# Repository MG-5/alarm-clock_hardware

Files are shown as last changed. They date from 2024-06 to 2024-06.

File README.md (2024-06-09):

# alarm-clock_v3
Hardware for alarm clock with VFD display

### Requirements for rev 1.0
* 24V input
* efficient boost converter up to 40V
* control VFD display with multiplexing & dimming
* control 24V CCT-LED strip (cold/neutral/warm white) with PWM
* I²C interface
  * DS3231 as RTC
* connection to ESP (UART)
* battery-backup

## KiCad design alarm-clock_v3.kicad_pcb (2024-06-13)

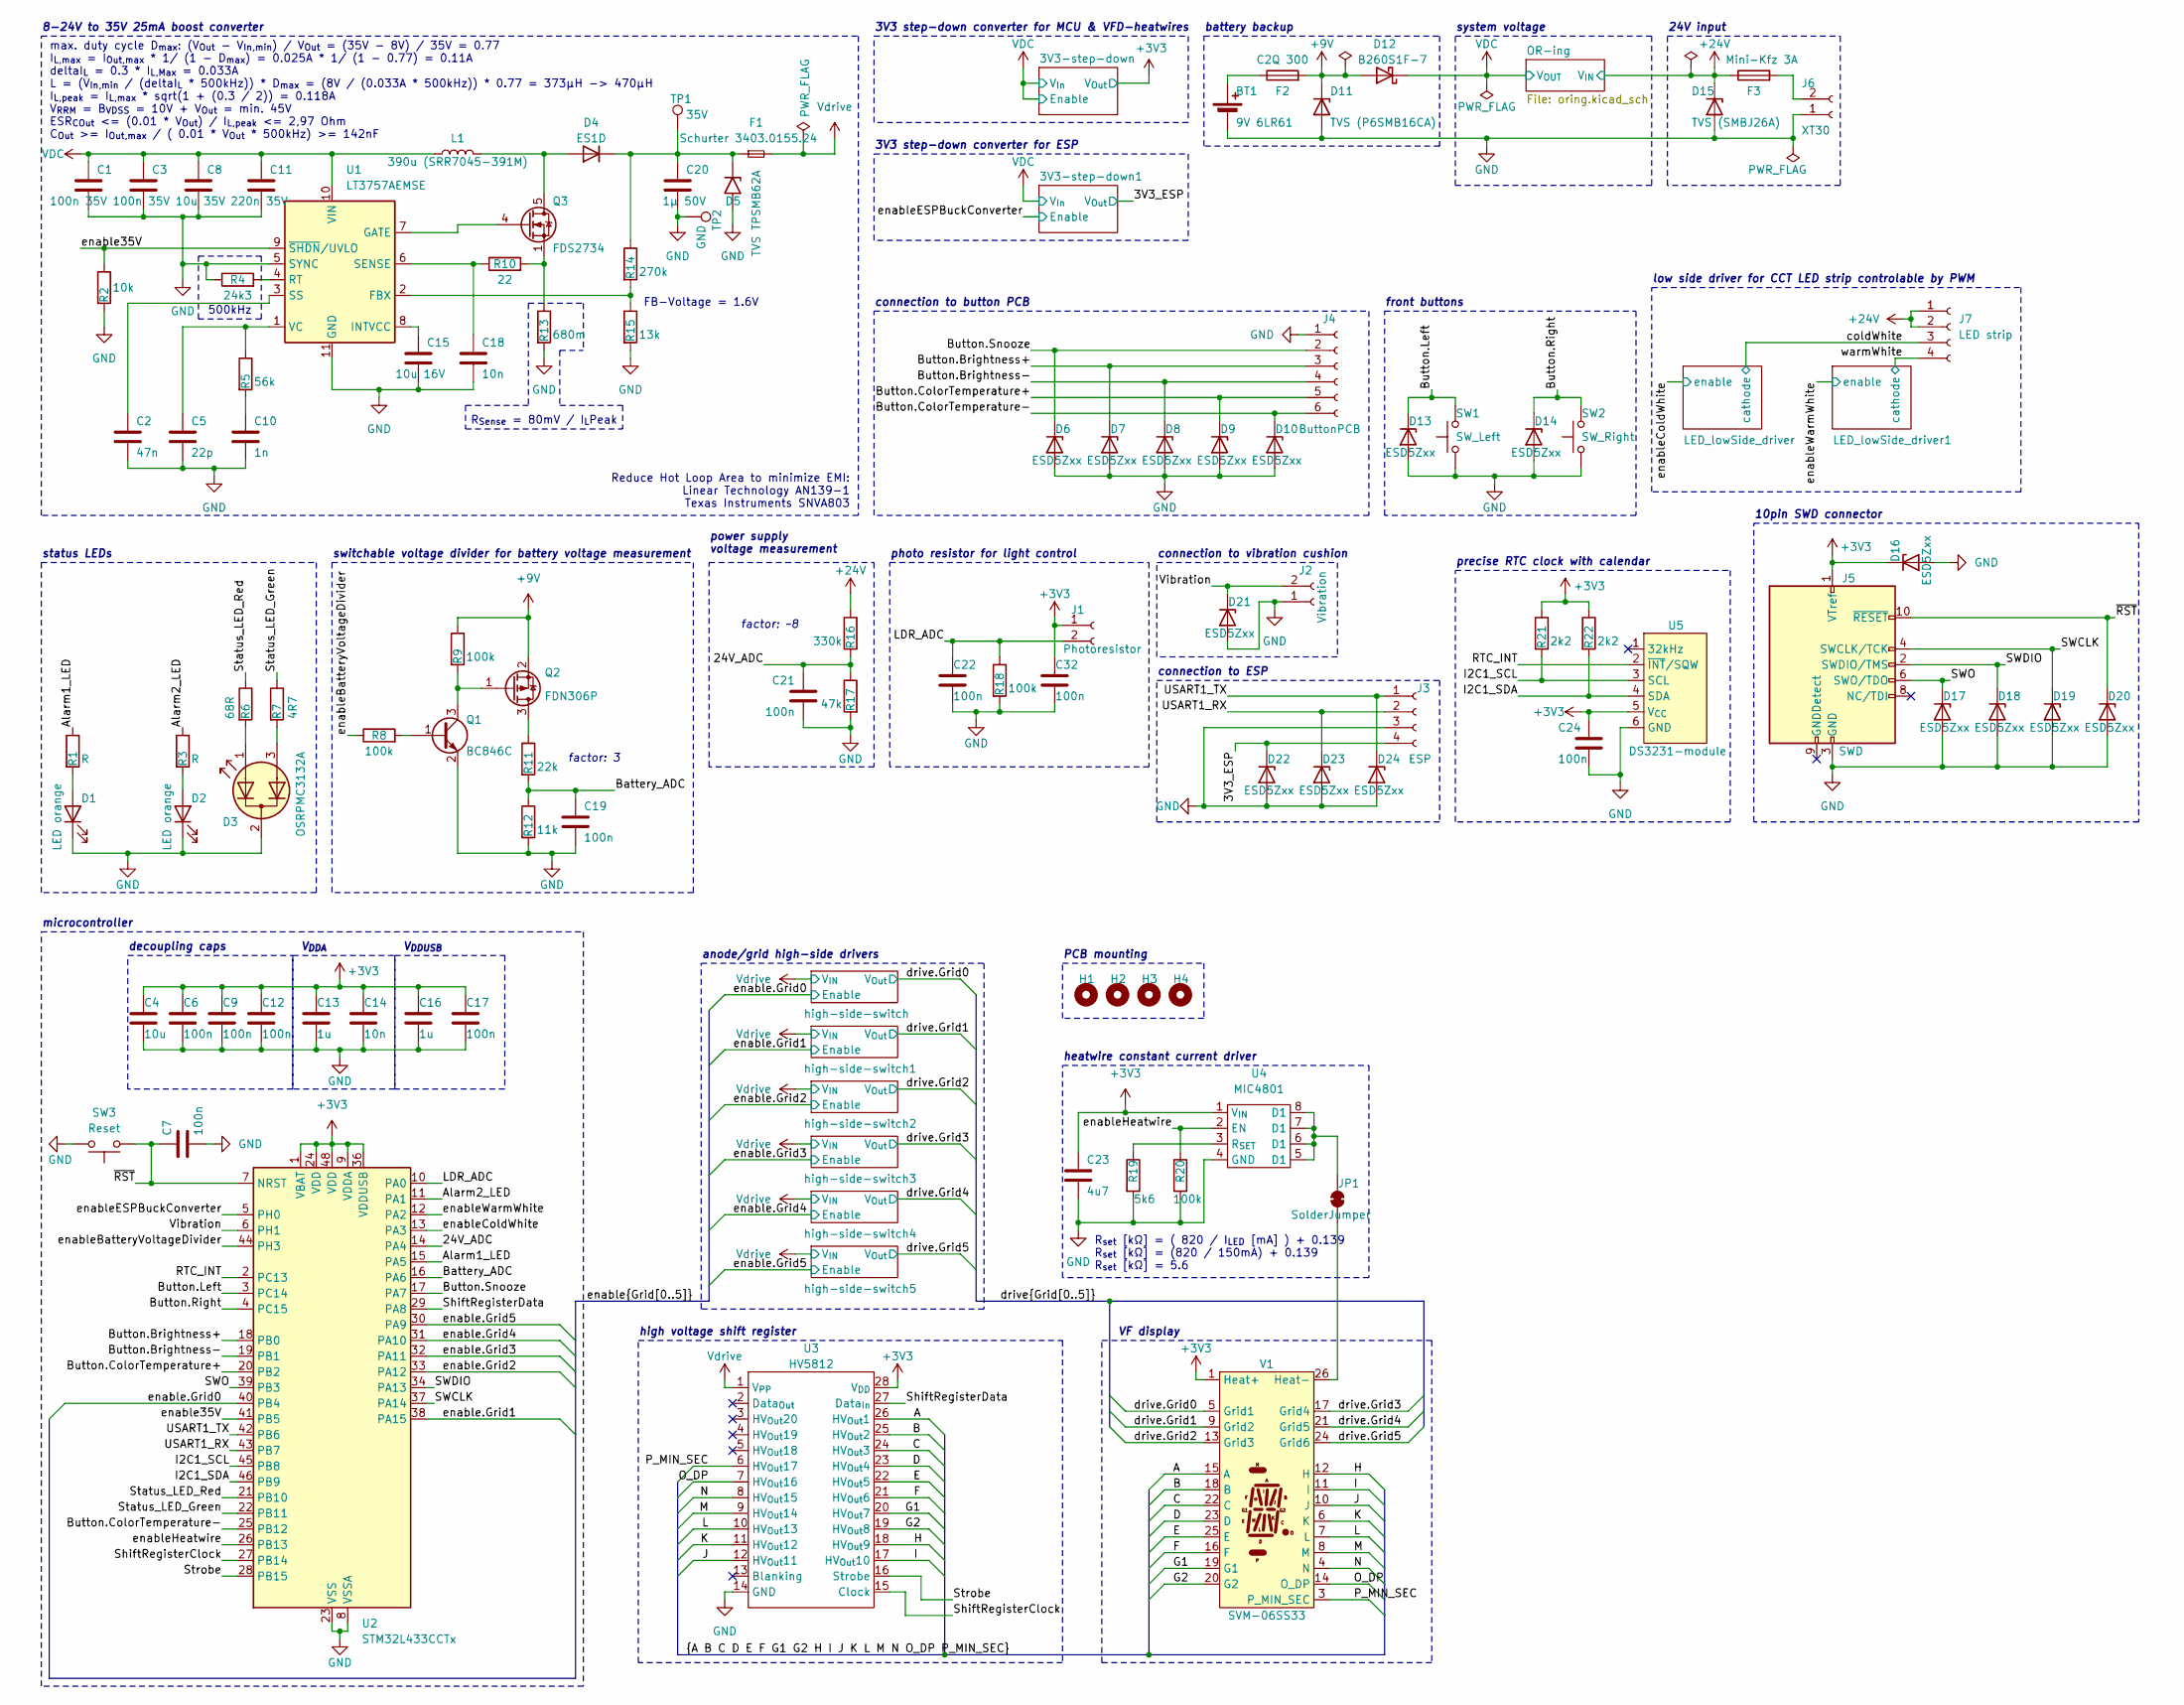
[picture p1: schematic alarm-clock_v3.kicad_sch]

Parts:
BT1: 9V 6LR61; Molex_PicoBlade_53047-0210_1x02_P1.25mm_Vertical
C1, C3: 100n 35V; C_0603_1608Metric_Pad1.08x0.95mm_HandSolder
C2: 47n; C_0603_1608Metric_Pad1.08x0.95mm_HandSolder
C4: 10u; C_0805_2012Metric_Pad1.18x1.45mm_HandSolder
C5: 22p; C_0402_1005Metric_Pad0.74x0.62mm_HandSolder
C6, C7, C9, C12, C17, C19, C21, C22, C24, C32: 100n; C_0603_1608Metric_Pad1.08x0.95mm_HandSolder
C8: 10u 35V; C_1206_3216Metric_Pad1.33x1.80mm_HandSolder
C10: 1n; C_0603_1608Metric_Pad1.08x0.95mm_HandSolder
C11: 220n 35V; C_0805_2012Metric_Pad1.18x1.45mm_HandSolder
C13, C16: 1u; C_0603_1608Metric_Pad1.08x0.95mm_HandSolder
C14: 10n; C_0603_1608Metric_Pad1.08x0.95mm_HandSolder
C15: 10u 16V; C_0805_2012Metric_Pad1.18x1.45mm_HandSolder
C18: 10n; C_0805_2012Metric_Pad1.18x1.45mm_HandSolder
C20: 1µ 50V; C_0805_2012Metric_Pad1.18x1.45mm_HandSolder
C23: 4u7; C_0603_1608Metric_Pad1.08x0.95mm_HandSolder
D1, D2: LED orange; PinHeader_1x02_P2.54mm_Vertical
D3: OSRPMC3132A; PinHeader_1x03_P2.54mm_Vertical
D4: ES1D; D_SMA_Handsoldering
D5: TVS TPSMB62A; D_SMF
D6, D7, D8, D9, D10, D13, D14, D16, D17, D18, D19, D20, D21, D22, D23, D24: ESD5Zxx; D_SOD-523
D11: TVS (P6SMB16CA); D_SMB_Handsoldering
D12: B260S1F-7; D_SOD-123
D15: TVS (SMBJ26A); D_SMB_Handsoldering
F1: Schurter 3403.0155.24; Fuse_Schurter_UMT250
F2: C2Q 300; Fuse_0603_1608Metric_Pad1.05x0.95mm_HandSolder
F3: Mini-Kfz 3A; KEYSTONE-FUSE-3557-2
H1, H2, H3, H4: MountingHole; MountingHole_3.2mm_M3_ISO14580
J1: Photoresistor; Molex_PicoBlade_53047-0210_1x02_P1.25mm_Vertical
J2: Vibration; Molex_PicoBlade_53047-0210_1x02_P1.25mm_Vertical
J3: ESP; Molex_PicoBlade_53047-0410_1x04_P1.25mm_Vertical
J4: ButtonPCB; Molex_PicoBlade_53047-0610_1x06_P1.25mm_Vertical
J5: SWD; PinHeader_2x05_P1.27mm_Vertical_SMD
J6: XT30; AMASS_XT30U-M_1x02_P5.0mm_Vertical
J7: LED strip; Molex_PicoBlade_53047-0410_1x04_P1.25mm_Vertical
JP1: SolderJumper; SolderJumper-2_P1.3mm_Open_TrianglePad1.0x1.5mm
L1: 390u (SRR7045-391M); L_7.3x7.3_H4.5
Q1: BC846C; SOT-23_Handsoldering
Q2: FDN306P; SOT-23_Handsoldering
Q3: FDS2734; SOIC-8_3.9x4.9mm_P1.27mm
R1, R3: R; R_0603_1608Metric_Pad0.98x0.95mm_HandSolder
R2: 10k; R_0603_1608Metric_Pad0.98x0.95mm_HandSolder
R4: 24k3; R_0603_1608Metric_Pad0.98x0.95mm_HandSolder
R5: 56k; R_0603_1608Metric_Pad0.98x0.95mm_HandSolder
R6: 68R; R_0603_1608Metric_Pad0.98x0.95mm_HandSolder
R7: 4R7; R_0603_1608Metric_Pad0.98x0.95mm_HandSolder
R8, R9, R18, R20: 100k; R_0603_1608Metric_Pad0.98x0.95mm_HandSolder
R10: 22; R_0603_1608Metric_Pad0.98x0.95mm_HandSolder
R11: 22k; R_0603_1608Metric_Pad0.98x0.95mm_HandSolder
R12: 11k; R_0603_1608Metric_Pad0.98x0.95mm_HandSolder
R13: 680m; R_0603_1608Metric_Pad0.98x0.95mm_HandSolder
R14: 270k; R_0603_1608Metric_Pad0.98x0.95mm_HandSolder
R15: 13k; R_0603_1608Metric_Pad0.98x0.95mm_HandSolder
R16: 330k; R_0603_1608Metric_Pad0.98x0.95mm_HandSolder
R17: 47k; R_0603_1608Metric_Pad0.98x0.95mm_HandSolder
R19: 5k6; R_0603_1608Metric_Pad0.98x0.95mm_HandSolder
R21, R22: 2k2; R_0603_1608Metric_Pad0.98x0.95mm_HandSolder
SW1: SW_Left; SW_SPST_PTS810
SW2: SW_Right; SW_SPST_PTS810
SW3: Reset; SW_SPST_PTS810
TP1: 35V; TestPoint_THTPad_D1.5mm_Drill0.7mm
TP2: GND; TestPoint_THTPad_D1.5mm_Drill0.7mm
U1: LT3757AEMSE; MSOP-10-1EP_3x3mm_P0.5mm_EP1.68x1.88mm
U2: STM32L433CCTx; LQFP-48_7x7mm_P0.5mm
U3: HV5812; SOIC-28W_7.5x17.9mm_P1.27mm
U4: MIC4801; PowerIntegrations_SO-8
U5: DS3231-module
V1: SVM-06SS33

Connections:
+3V3: C4.1, C6.1, C9.1, C12.1, C13.1, C14.1, C16.1, C17.1, C23.1, C24.1, C32.1, D16.1 (K), J1.1, J5.1 (VTref), R21.1, R22.1, U2.1 (VBAT), U2.9 (VDDA), U2.24 (VDD), U2.36 (VDDUSB), U2.48 (VDD), U3.28 (V_{DD}), U4.1 (V_{IN}), U5.5 (V_{CC}), V1.1 (Heat+), V1.2 (Heat+); also elsewhere on the board
+9V: D11.1 (K), D12.2 (A), F2.2, Q2.2 (S), R9.1
+24V: D15.1 (K), F3.1, J7.1, J7.2, R16.1; also elsewhere on the board
/3V3_ESP: D22.1 (K), J3.4; also elsewhere on the board
/24V_ADC: C21.1, R16.2, R17.1, U2.14 (PA4)
/A: U3.26 (HV_{Out}1), V1.15 (A)
/Alarm1_LED: R1.1, U2.15 (PA5)
/Alarm2_LED: R3.1, U2.11 (PA1)
/B: U3.25 (HV_{Out}2), V1.18 (B)
/Battery_ADC: C19.1, R11.2, R12.1, U2.16 (PA6)
/Button.Brightness+: D7.1 (K), J4.3, U2.18 (PB0)
/Button.Brightness-: D8.1 (K), J4.4, U2.19 (PB1)
/Button.ColorTemperature+: D9.1 (K), J4.5, U2.20 (PB2)
/Button.ColorTemperature-: D10.1 (K), J4.6, U2.25 (PB12)
/Button.Left: D13.1 (K), SW1.2, U2.3 (PC14)
/Button.Right: D14.1 (K), SW2.2, U2.4 (PC15)
/Button.Snooze: D6.1 (K), J4.2, U2.17 (PA7)
/C: U3.24 (HV_{Out}3), V1.22 (C)
/D: U3.23 (HV_{Out}4), V1.23 (D)
/E: U3.22 (HV_{Out}5), V1.25 (E)
/F: U3.21 (HV_{Out}6), V1.16 (F)
/G1: U3.20 (HV_{Out}7), V1.19 (G1)
/G2: U3.19 (HV_{Out}8), V1.20 (G2)
/H: U3.18 (HV_{Out}9), V1.12 (H)
/I: U3.17 (HV_{Out}10), V1.11 (I)
/I2C1_SCL: R21.2, U2.45 (PB8), U5.3 (SCL)
/I2C1_SDA: R22.2, U2.46 (PB9), U5.4 (SDA)
/J: U3.12 (HV_{Out}11), V1.10 (J)
/K: U3.11 (HV_{Out}12), V1.6 (K)
/L: U3.10 (HV_{Out}13), V1.7 (L)
/LDR_ADC: C22.1, J1.2, R18.1, U2.10 (PA0)
/M: U3.9 (HV_{Out}14), V1.8 (M)
/N: U3.8 (HV_{Out}15), V1.4 (N)
/O_DP: U3.7 (HV_{Out}16), V1.14 (O_DP)
/P_MIN_SEC: U3.6 (HV_{Out}17), V1.3 (P_MIN_SEC)
/RTC_INT: U2.2 (PC13), U5.2 (~INT/SQW)
/SWCLK: D19.1 (K), J5.4 (SWCLK/TCK), U2.37 (PA14)
/SWDIO: D18.1 (K), J5.2 (SWDIO/TMS), U2.34 (PA13)
/SWO: D17.1 (K), J5.6 (SWO/TDO), U2.39 (PB3)
/ShiftRegisterClock: U2.27 (PB14), U3.15 (Clock)
/ShiftRegisterData: U2.29 (PA8), U3.27 (Data_{In})
/Status_LED_Green: R7.1, U2.22 (PB11)
/Status_LED_Red: R6.1, U2.21 (PB10)
/Strobe: U2.28 (PB15), U3.16 (Strobe)
/USART1_RX: D23.1 (K), J3.2, U2.43 (PB7)
/USART1_TX: D24.1 (K), J3.1, U2.42 (PB6)
/Vibration: D21.1 (K), J2.2, U2.6 (PH1)
/coldWhite: J7.3; also elsewhere on the board
/drive.Grid0: V1.5 (Grid1); also elsewhere on the board
/drive.Grid1: V1.9 (Grid2); also elsewhere on the board
/drive.Grid2: V1.13 (Grid3); also elsewhere on the board
/drive.Grid3: V1.17 (Grid4); also elsewhere on the board
/drive.Grid4: V1.21 (Grid5); also elsewhere on the board
/drive.Grid5: V1.24 (Grid6); also elsewhere on the board
/enable35V: R2.1, U1.9 (~SHDN/UVLO), U2.41 (PB5)
/enable.Grid0: U2.40 (PB4); also elsewhere on the board
/enable.Grid1: U2.38 (PA15); also elsewhere on the board
/enable.Grid2: U2.33 (PA12); also elsewhere on the board
/enable.Grid3: U2.32 (PA11); also elsewhere on the board
/enable.Grid4: U2.31 (PA10); also elsewhere on the board
/enable.Grid5: U2.30 (PA9); also elsewhere on the board
/enableBatteryVoltageDivider: R8.1, U2.44 (PH3)
/enableColdWhite: U2.13 (PA3); also elsewhere on the board
/enableESPBuckConverter: U2.5 (PH0); also elsewhere on the board
/enableHeatwire: R20.1, U2.26 (PB13), U4.2 (EN)
/enableWarmWhite: U2.12 (PA2); also elsewhere on the board
/warmWhite: J7.4; also elsewhere on the board
/~RST: C7.1, D20.1 (K), J5.10 (~RESET), SW3.1, U2.7 (NRST)
GND: BT1.2 (-), C1.2, C2.2, C3.2, C4.2, C5.2, C6.2, C7.2, C8.2, C9.2, C10.2, C11.2, C12.2, C13.2, C14.2, C15.2, C16.2, C17.2, C18.2, C19.2, C20.2, C21.2, C22.2, C23.2, C24.2, C32.2, D1.1 (K), D2.1 (K), D3.2 (K), D5.2 (A2), D6.2 (A), D7.2 (A), D8.2 (A), D9.2 (A), D10.2 (A), D11.2 (A), D13.2 (A), D14.2 (A), D15.2 (A), D16.2 (A), D17.2 (A), D18.2 (A), D19.2 (A), D20.2 (A), D21.2 (A), D22.2 (A), D23.2 (A), D24.2 (A), J2.1, J3.3, J4.1, J5.3 (GND), J5.5 (GND), J6.1, Q1.2 (E), R2.2, R4.1, R12.2, R13.2, R15.2, R17.2, R18.2, R19.2, R20.2, SW1.1, SW2.1, SW3.2, TP2.1, U1.5 (SYNC), U1.11 (GND), U2.8 (VSSA), U2.23 (VSS), U2.35 (VSS), U2.47 (VSS), U3.14 (GND), U4.4 (GND), U5.6 (GND); also elsewhere on the board
unnamed: BT1.1 (+), F2.1
unnamed: C10.1, R5.2
unnamed: D1.2 (A), R1.2
unnamed: D2.2 (A), R3.2
unnamed: D3.1 (A1), R6.2
unnamed: D3.3 (A2), R7.2
unnamed: D4.2 (A), L1.2, Q3.5 (D), Q3.6 (D), Q3.7 (D), Q3.8 (D)
unnamed: C20.1, D4.1 (K), D5.1 (A1), F1.1, R14.1, TP1.1
unnamed: F3.2, J6.2
unnamed: JP1.1 (A), U4.5 (D1), U4.6 (D1), U4.7 (D1), U4.8 (D1)
unnamed: JP1.2 (B), V1.26 (Heat-)
unnamed: Q1.1 (B), R8.2
unnamed: Q1.3 (C), Q2.1 (G), R9.2
unnamed: Q2.3 (D), R11.1
unnamed: Q3.4 (G), U1.7 (GATE)
unnamed: Q3.1 (S), Q3.2 (S), Q3.3 (S), R10.2, R13.1
unnamed: R14.2, R15.1, U1.2 (FBX)
unnamed: C15.1, U1.8 (INTVCC)
unnamed: R4.2, U1.4 (RT)
unnamed: C18.1, R10.1, U1.6 (SENSE)
unnamed: C2.1, U1.3 (SS)
unnamed: C5.1, R5.1, U1.1 (VC)
unnamed: R19.1, U4.3 (R_{SET})
VDC: C1.1, C3.1, C8.1, C11.1, D12.1 (K), L1.1, U1.10 (VIN); also elsewhere on the board
Vdrive: F1.2, U3.1 (V_{PP}); also elsewhere on the board

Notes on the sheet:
24V input
decoupling caps
factor: 3
microcontroller
V_{DDUSB}
factor: ~8
heatwire constant current driver
status LEDs
8-24V to 35V 25mA boost converter
system voltage
connection to ESP
power supply voltage measurement
R_{Sense} = 80mV / I_{L}Peak
3V3 step-down converter for MCU & VFD-heatwires
front buttons
Reduce Hot Loop Area to minimize EMI: Linear Technology AN139-1 Texas Instruments SNVA803
PCB mounting
battery backup
connection to button PCB
precise RTC clock with calendar
photo resistor for light control
low side driver for CCT LED strip controlable by PWM
3V3 step-down converter for ESP
500kHz
high voltage shift register
FB-Voltage = 1.6V
anode/grid high-side drivers
10pin SWD connector
R_{set} [kΩ] = ( 820 / I_{LED} [mA] ) + 0.139 R_{set} [kΩ] = (820 / 150mA) + 0.139 R_{set} [kΩ] = 5.6
connection to vibration cushion
VF display
switchable voltage divider for battery voltage measurement
max. duty cycle D_{max}: (V_{Out} - V_{In,min}) / V_{Out} = (35V - 8V) / 35V = 0.77 I_{L,max} = I_{Out,max} * 1/ (1 - D_{max}) = 0.025A * 1/ (1 - 0.77) = 0.11A deltaI_{L} = 0.3 * I_{L,Max} = 0.033A L = (V_{In,min} / (deltaI_{L} * 500kHz)) * D_{max} = (8V / (0.033A * 500kHz)) * 0.77 = 373µH -> 470µH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
V_{DDA}

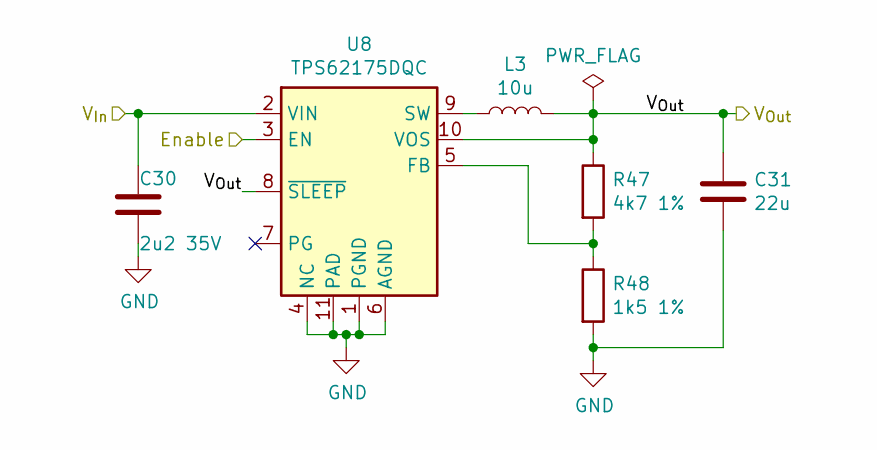
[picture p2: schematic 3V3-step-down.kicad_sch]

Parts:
C30: 2u2 35V; C_0603_1608Metric_Pad1.08x0.95mm_HandSolder
C31: 22u; C_0805_2012Metric_Pad1.18x1.45mm_HandSolder
L3: 10u; L_1210_3225Metric
R47: 4k7 1%; R_0603_1608Metric_Pad0.98x0.95mm_HandSolder
R48: 1k5 1%; R_0603_1608Metric_Pad0.98x0.95mm_HandSolder
U8: TPS62175DQC; WSON-10-1EP_2x3mm_P0.5mm_EP0.84x2.4mm_ThermalVias

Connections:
/3V3_ESP: C31.1, L3.2, R47.1, U8.8 (~SLEEP), U8.10 (VOS); also elsewhere on the board
/enableESPBuckConverter: U8.3 (EN); also elsewhere on the board
GND: C30.2, C31.2, R48.2, U8.1 (PGND), U8.4 (NC), U8.6 (AGND), U8.11 (PAD); also elsewhere on the board
unnamed: R47.2, R48.1, U8.5 (FB)
unnamed: L3.1, U8.9 (SW)
VDC: C30.1, U8.2 (VIN); also elsewhere on the board

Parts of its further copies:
C28: 2u2 35V; C_0603_1608Metric_Pad1.08x0.95mm_HandSolder
C29: 22u; C_0805_2012Metric_Pad1.18x1.45mm_HandSolder
L2: 10u; L_1210_3225Metric
R45: 4k7 1%; R_0603_1608Metric_Pad0.98x0.95mm_HandSolder
R46: 1k5 1%; R_0603_1608Metric_Pad0.98x0.95mm_HandSolder
U7: TPS62175DQC; WSON-10-1EP_2x3mm_P0.5mm_EP0.84x2.4mm_ThermalVias

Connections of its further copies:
+3V3: C29.1, L2.2, R45.1, U7.8 (~SLEEP), U7.10 (VOS); also elsewhere on the board
GND: C28.2, C29.2, R46.2, U7.1 (PGND), U7.4 (NC), U7.6 (AGND), U7.11 (PAD); also elsewhere on the board
unnamed: R45.2, R46.1, U7.5 (FB)
unnamed: L2.1, U7.9 (SW)
VDC: C28.1, U7.2 (VIN), U7.3 (EN); also elsewhere on the board

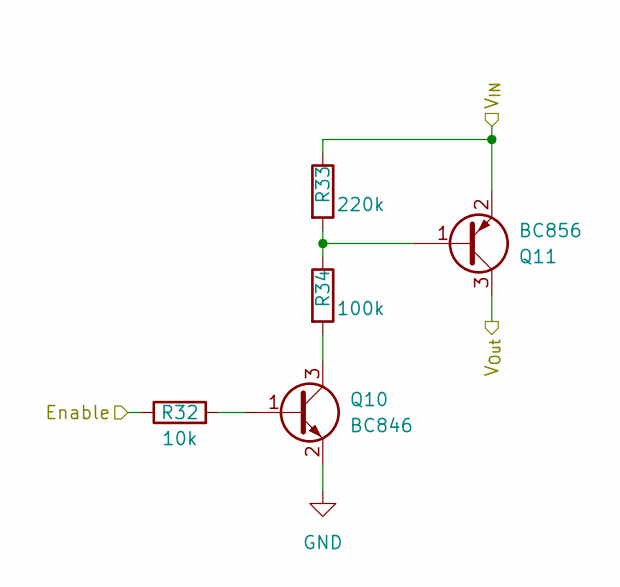
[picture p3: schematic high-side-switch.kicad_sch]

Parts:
Q10: BC846; SOT-23_Handsoldering
Q11: BC856; SOT-23_Handsoldering
R32: 10k; R_0603_1608Metric_Pad0.98x0.95mm_HandSolder
R33: 220k; R_0603_1608Metric_Pad0.98x0.95mm_HandSolder
R34: 100k; R_0603_1608Metric_Pad0.98x0.95mm_HandSolder

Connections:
/drive.Grid3: Q11.3 (C); also elsewhere on the board
/enable.Grid3: R32.1; also elsewhere on the board
GND: Q10.2 (E); also elsewhere on the board
unnamed: Q10.1 (B), R32.2
unnamed: Q10.3 (C), R34.2
unnamed: Q11.1 (B), R33.2, R34.1
Vdrive: Q11.2 (E), R33.1; also elsewhere on the board

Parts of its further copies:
Q4, Q6, Q8, Q12, Q14: BC846; SOT-23_Handsoldering
Q5, Q7, Q9, Q13, Q15: BC856; SOT-23_Handsoldering
R23, R26, R29, R35, R38: 10k; R_0603_1608Metric_Pad0.98x0.95mm_HandSolder
R24, R27, R30, R36, R39: 220k; R_0603_1608Metric_Pad0.98x0.95mm_HandSolder
R25, R28, R31, R37, R40: 100k; R_0603_1608Metric_Pad0.98x0.95mm_HandSolder

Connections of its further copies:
/drive.Grid0: Q5.3 (C); also elsewhere on the board
/drive.Grid1: Q7.3 (C); also elsewhere on the board
/drive.Grid2: Q9.3 (C); also elsewhere on the board
/drive.Grid4: Q13.3 (C); also elsewhere on the board
/drive.Grid5: Q15.3 (C); also elsewhere on the board
/enable.Grid0: R23.1; also elsewhere on the board
/enable.Grid1: R26.1; also elsewhere on the board
/enable.Grid2: R29.1; also elsewhere on the board
/enable.Grid4: R35.1; also elsewhere on the board
/enable.Grid5: R38.1; also elsewhere on the board
GND: Q4.2 (E), Q6.2 (E), Q8.2 (E), Q12.2 (E), Q14.2 (E); also elsewhere on the board
unnamed: Q4.1 (B), R23.2
unnamed: Q4.3 (C), R25.2
unnamed: Q5.1 (B), R24.2, R25.1
unnamed: Q6.1 (B), R26.2
unnamed: Q6.3 (C), R28.2
unnamed: Q7.1 (B), R27.2, R28.1
unnamed: Q8.1 (B), R29.2
unnamed: Q8.3 (C), R31.2
unnamed: Q9.1 (B), R30.2, R31.1
unnamed: Q12.1 (B), R35.2
unnamed: Q12.3 (C), R37.2
unnamed: Q13.1 (B), R36.2, R37.1
unnamed: Q14.1 (B), R38.2
unnamed: Q14.3 (C), R40.2
unnamed: Q15.1 (B), R39.2, R40.1
Vdrive: Q5.2 (E), Q7.2 (E), Q9.2 (E), Q13.2 (E), Q15.2 (E), R24.1, R27.1, R30.1, R36.1, R39.1; also elsewhere on the board

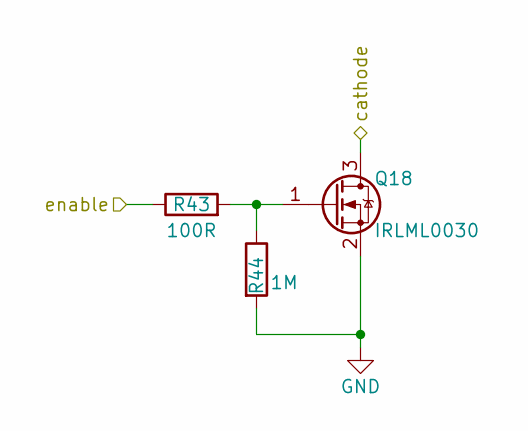
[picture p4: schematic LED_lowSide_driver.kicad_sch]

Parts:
Q18: IRLML0030; SOT-23_Handsoldering
R43: 100R; R_0603_1608Metric_Pad0.98x0.95mm_HandSolder
R44: 1M; R_0603_1608Metric_Pad0.98x0.95mm_HandSolder

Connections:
/enableWarmWhite: R43.1; also elsewhere on the board
/warmWhite: Q18.3 (D); also elsewhere on the board
GND: Q18.2 (S), R44.2; also elsewhere on the board
unnamed: Q18.1 (G), R43.2, R44.1

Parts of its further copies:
Q17: IRLML0030; SOT-23_Handsoldering
R41: 100R; R_0603_1608Metric_Pad0.98x0.95mm_HandSolder
R42: 1M; R_0603_1608Metric_Pad0.98x0.95mm_HandSolder

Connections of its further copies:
/coldWhite: Q17.3 (D); also elsewhere on the board
/enableColdWhite: R41.1; also elsewhere on the board
GND: Q17.2 (S), R42.2; also elsewhere on the board
unnamed: Q17.1 (G), R41.2, R42.1

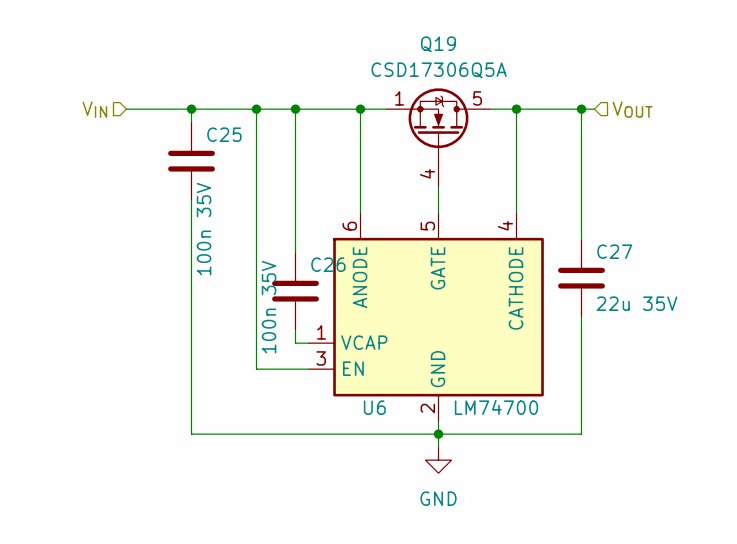
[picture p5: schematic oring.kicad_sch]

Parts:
C25, C26: 100n 35V; C_0603_1608Metric_Pad1.08x0.95mm_HandSolder
C27: 22u 35V; C_0805_2012Metric_Pad1.18x1.45mm_HandSolder
Q19: CSD17306Q5A; TDSON-8-1
U6: LM74700; SOT-23-6

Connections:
+24V: C25.1, C26.1, Q19.1 (S), Q19.2 (S), Q19.3 (S), U6.3 (EN), U6.6 (ANODE); also elsewhere on the board
GND: C25.2, C27.2, U6.2 (GND); also elsewhere on the board
unnamed: Q19.4 (G), U6.5 (GATE)
unnamed: C26.2, U6.1 (VCAP)
VDC: C27.1, Q19.5 (D), U6.4 (CATHODE); also elsewhere on the board

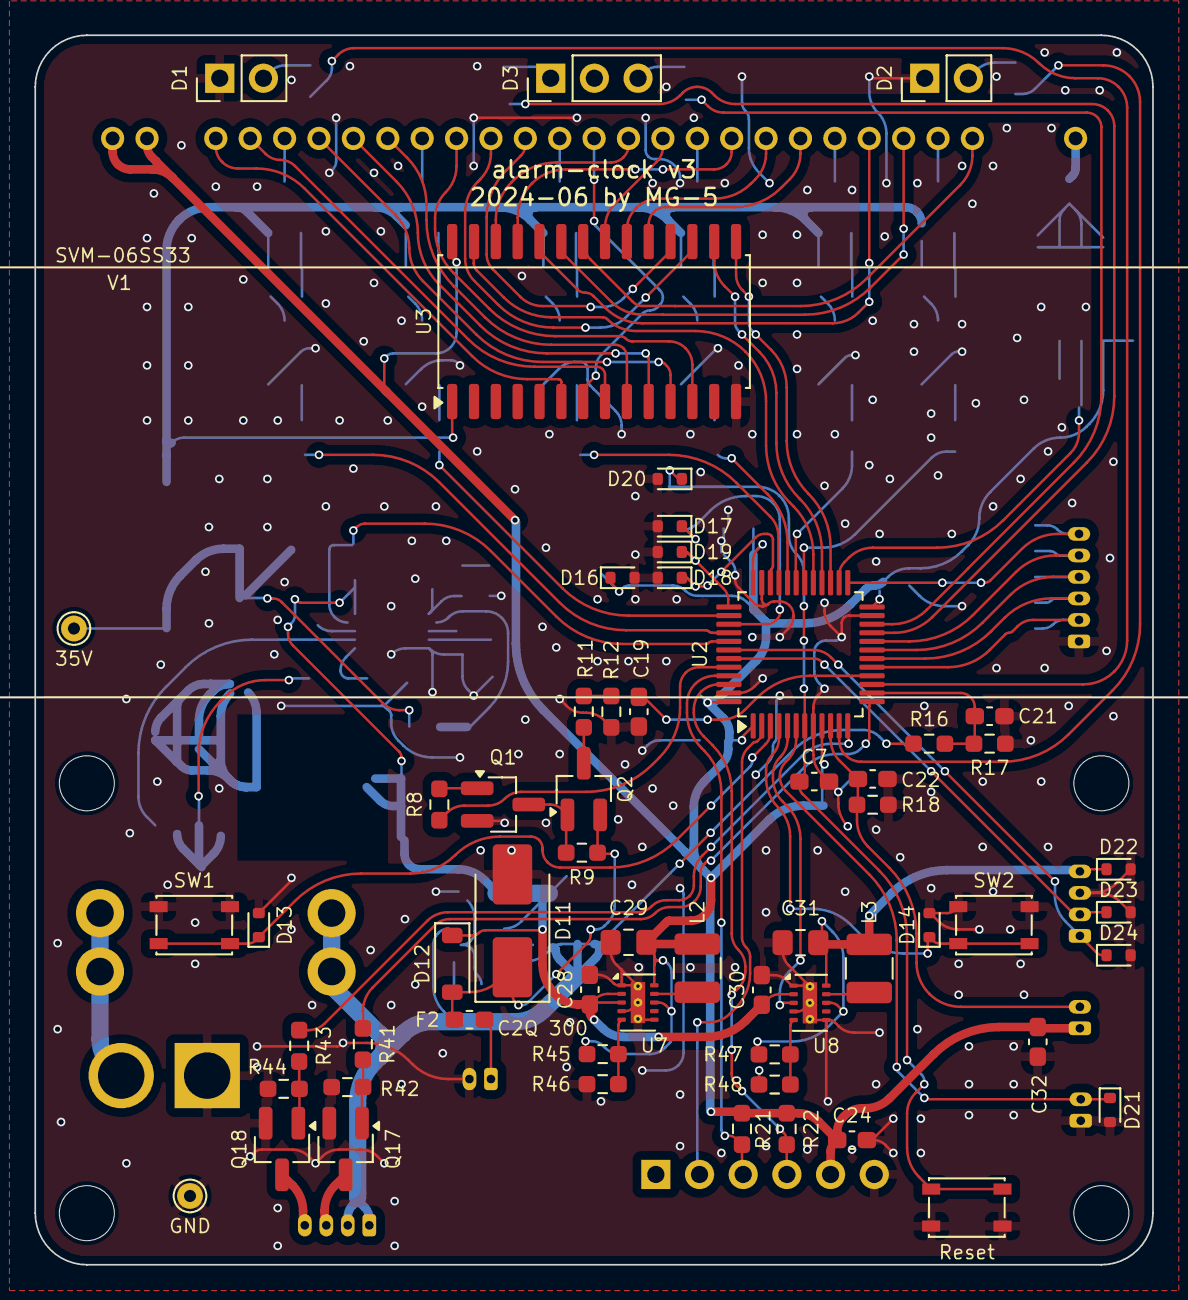
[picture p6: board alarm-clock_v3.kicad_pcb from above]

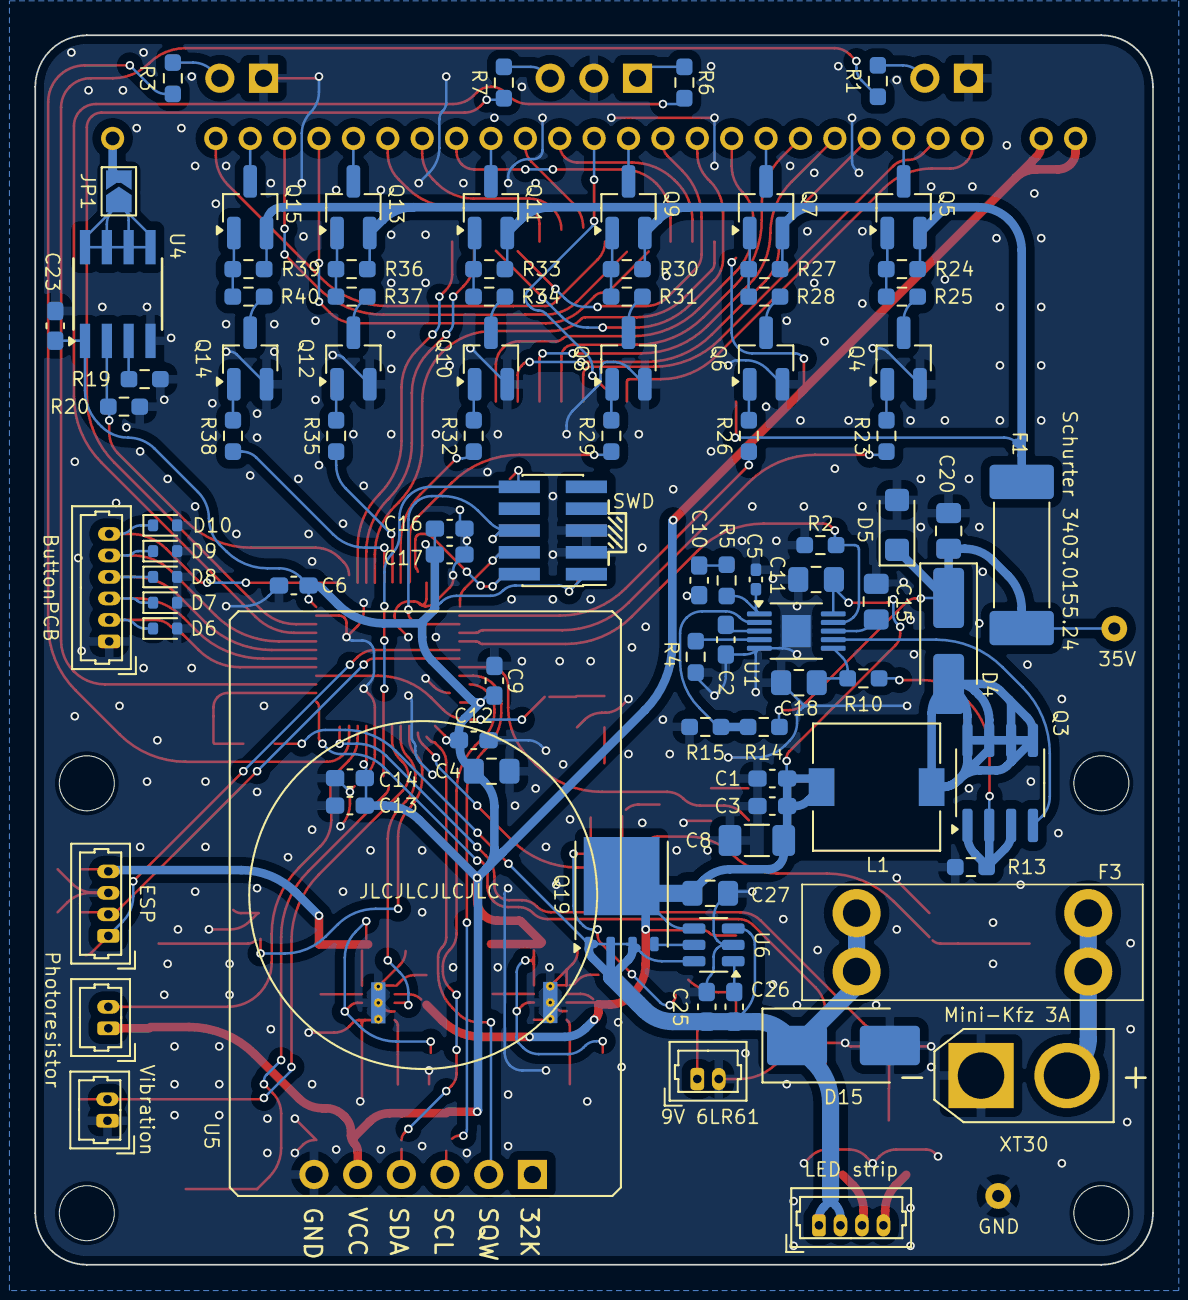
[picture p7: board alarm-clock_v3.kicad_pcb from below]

Board: 2 copper layers, 65.0 x 71.5 mm, 155 parts (91 on the bottom side), 120 nets.

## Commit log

2024-06-09 Add schematic
    [3V3-step-down.kicad_sch, LED_lowSide_driver.kicad_sch, alarm-clock_v3.kicad_sch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]
2024-06-09 Add PCB
    [alarm-clock_v3.kicad_pcb]
2024-06-13 Gerber settings
    [alarm-clock_v3.kicad_pcb]
